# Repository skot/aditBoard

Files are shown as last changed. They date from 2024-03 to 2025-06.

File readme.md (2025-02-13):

## aditBoard
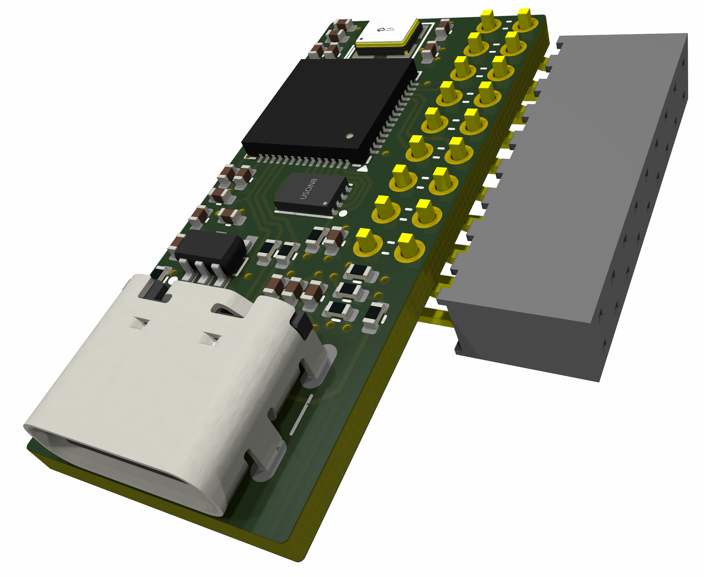
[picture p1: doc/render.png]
aditboard early render


The aditBoard is a USB adapter for Bitmain hashboards. It's based on the RaspberryPi RP2040.

The aditBoard is designed to work with the upcoming Bitcart USB, or standalone with a PC.

- For fan and PSU control check out the [AntHat](https://github.com/skot/anthat)
- Preliminary [firmware](https://github.com/The-256-Foundation/ember-one-firmware) for the aditBoard

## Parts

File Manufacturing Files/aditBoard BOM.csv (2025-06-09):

Qty | Reference | Value | PARTNO | LCSC Part
2 | C2 C4 | 30pF | 0402CG300J500NT | C1570
10 | C5 C6 C7 C10 C11 C12 C13 C14 C15 C16 | 0.1uF | CL05B104KB54PNC | C307331
2 | C8 C9 | 1uF | CL05A105KA5NQNC | C52923
2 | C17 C18 | 1uF | EMK105BJ105MV-F | C52923
2 | R2 R3 | 33 | 0402WGF330JTCE | C25105
1 | U3 | RP2040 | RP2040 | C2040
1 | U4 | AP2112K-3.3TRG1 | AP2112K-3.3TRG1 | C51118
1 | Y1 | 12MHz | X322512MSB4SI | C9002
1 | J2 | Hashboard0 | PM200-2-09-W-4.3 | C3012192
1 | J1 | USB_C_Receptacle_USB2.0 | USB4105-GF-A | C2988369
1 | U2 | W25X40CLUXIG TR | W25Q16JVUXIQ TR | C401661
1 | R1 | 10k | 0402WGF1002TCE | C25744
2 | R4 R5 | 5.1k | RMCF0402JT5K10 | C25905
3 | R25 R27 R29 | 4.7K | RC0805FR-074K7L | C25900

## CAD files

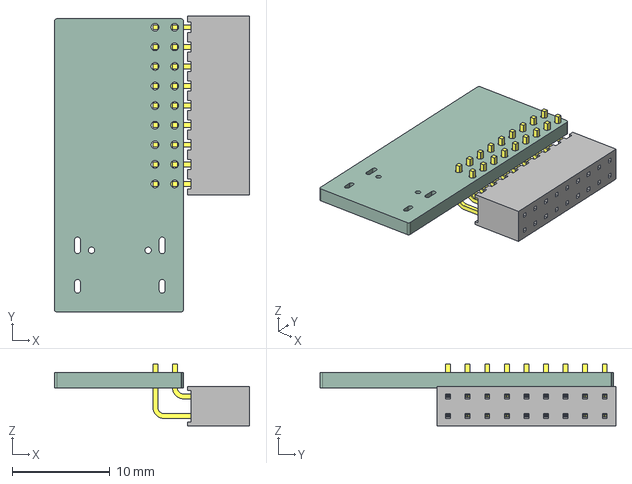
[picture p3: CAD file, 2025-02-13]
CAD/aditBoard.step
19.9 x 30.2 x 6.29 mm
SQT-109-01-F-D-RA
aditBoard_PCB

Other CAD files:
CAD/aditBoard.FCStd

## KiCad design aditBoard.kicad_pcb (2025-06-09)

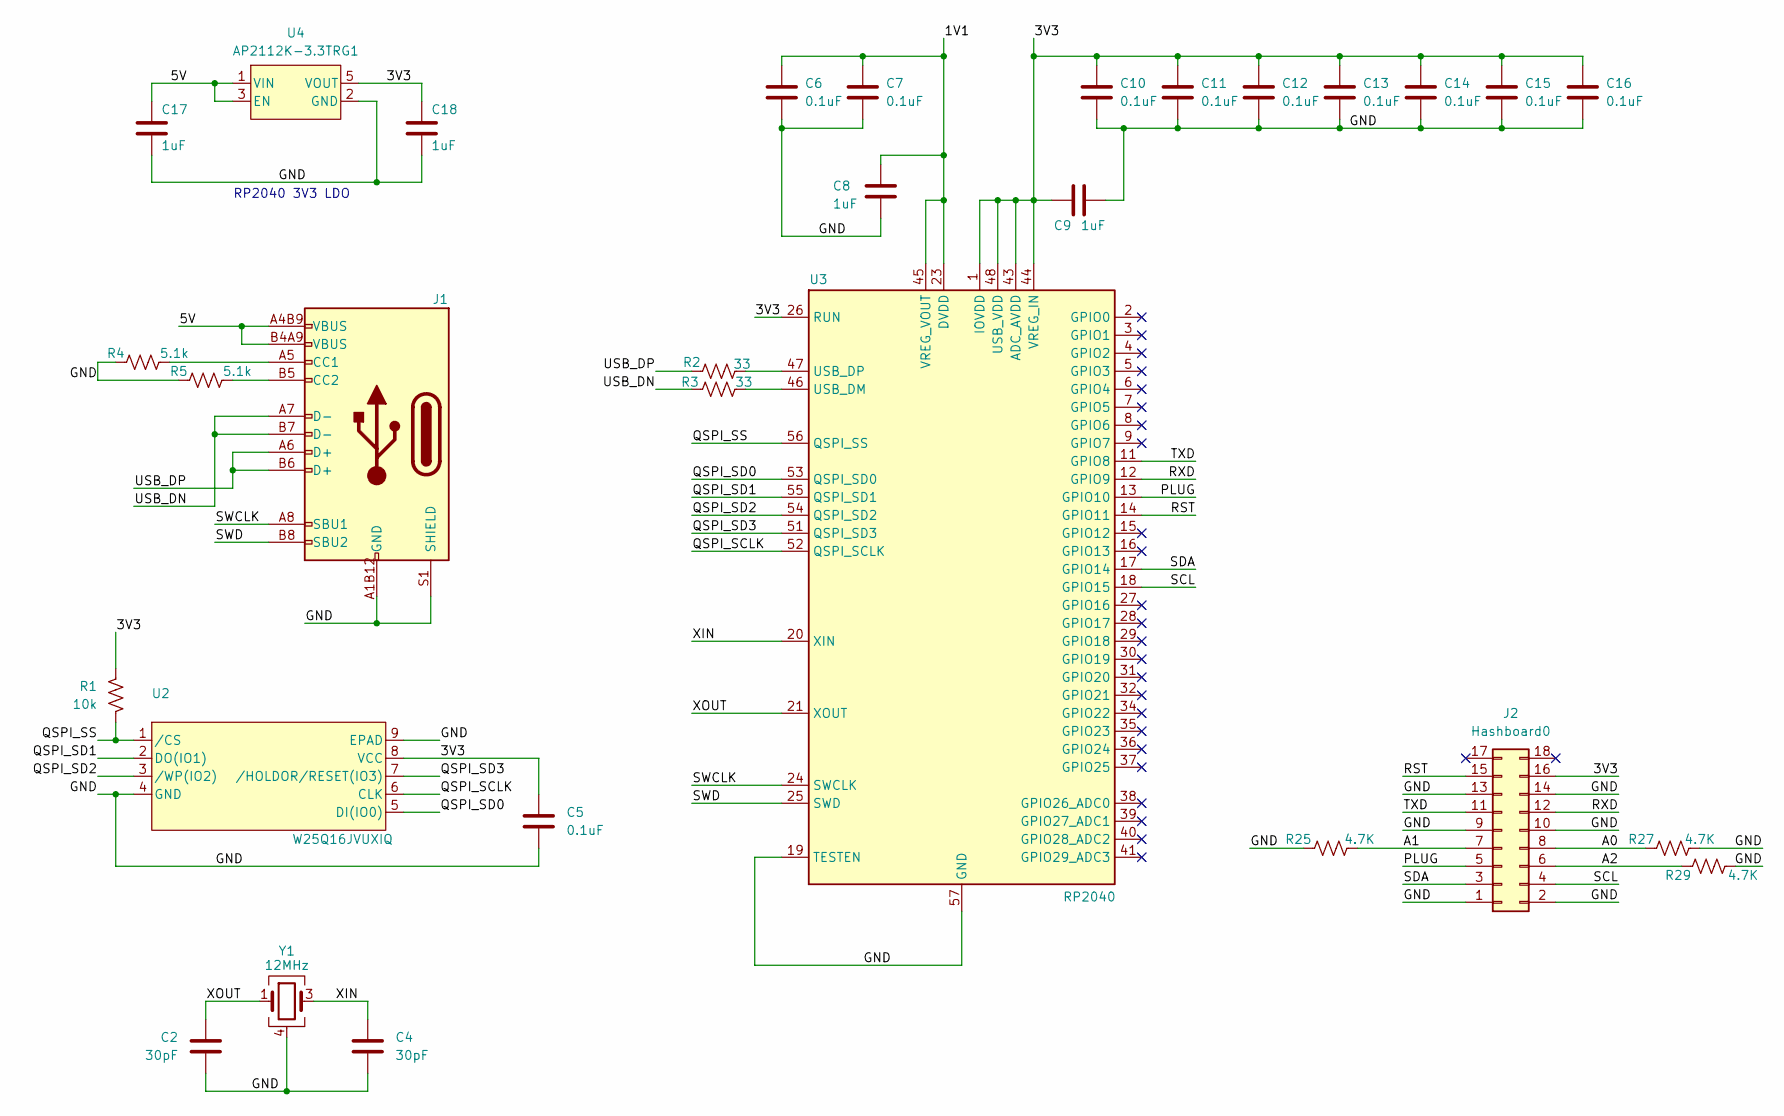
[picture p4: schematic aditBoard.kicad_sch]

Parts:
C2, C4: 30pF; C_0402_1005Metric; PARTNO 0402CG300J500NT; LCSC Part C1570
C5, C6, C7, C10, C11, C12, C13, C14, C15, C16: 0.1uF; C_0402_1005Metric; PARTNO CL05B104KB54PNC; LCSC Part C307331
C8, C9: 1uF; C_0402_1005Metric; PARTNO CL05A105KA5NQNC; LCSC Part C52923
C17, C18: 1uF; C_0402_1005Metric; PARTNO EMK105BJ105MV-F; LCSC Part C52923
J1: USB_C_Receptacle_USB2.0; USB_C_Receptacle_GCT_USB4105-xx-A_16P_TopMnt_Horizontal; PARTNO USB4105-GF-A; LCSC Part C2988369
J2: Hashboard0; PinHeader_2x09_P2.00mm_Horizontal; PARTNO PM200-2-09-W-4.3; LCSC Part C3012192
R1: 10k; R_0402_1005Metric; PARTNO 0402WGF1002TCE; LCSC Part C25744
R2, R3: 33; R_0402_1005Metric; PARTNO 0402WGF330JTCE; LCSC Part C25105
R4, R5: 5.1k; R_0402_1005Metric; PARTNO RMCF0402JT5K10; LCSC Part C25905
R25, R27, R29: 4.7K; R_0402_1005Metric; PARTNO RC0805FR-074K7L; LCSC Part C25900
U2: W25Q16JVUXIQ; USON8_L2.0-W3.0-P0.50-BL-EP; PARTNO W25Q16JVUXIQ; LCSC C2843335
U3: RP2040; QFN-56-1EP_7x7mm_P0.4mm_EP3.2x3.2mm; PARTNO RP2040; LCSC Part C2040
U4: AP2112K-3.3TRG1; SOT-25-5_L2.9-W1.6-P0.95-LS2.8-BL; PARTNO AP2112K-3.3TRG1; LCSC Part C51118
Y1: 12MHz; OSC-SMD_4P-L3.2-W2.5-BL; PARTNO X322512MSB4SI; LCSC Part C9002

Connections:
/1V1: C6.2, C7.2, C8.2, U3.23 (DVDD), U3.45 (VREG_VOUT), U3.50 (DVDD)
/3V3: C5.2, C9.1, C10.2, C11.2, C12.2, C13.2, C14.2, C15.2, C16.2, C18.1, J2.16, R1.1, U2.8 (VCC), U3.1 (IOVDD), U3.10 (IOVDD), U3.22 (IOVDD), U3.26 (RUN), U3.33 (IOVDD), U3.42 (IOVDD), U3.43 (ADC_AVDD), U3.44 (VREG_IN), U3.48 (USB_VDD), U3.49 (IOVDD), U4.5 (VOUT)
/5V: C17.1, J1.A4B9 (VBUS), J1.B4A9 (VBUS), U4.1 (VIN), U4.3 (EN)
/A0: J2.8, R27.1
/A1: J2.7, R25.2
/A2: J2.6, R29.1
/GND: C2.1, C4.1, C5.1, C6.1, C7.1, C8.1, C9.2, C10.1, C11.1, C12.1, C13.1, C14.1, C15.1, C16.1, C17.2, C18.2, J1.A1B12 (GND), J1.B1A12 (GND), J1.S1 (SHIELD), J2.1, J2.2, J2.9, J2.10, J2.13, J2.14, R4.1, R5.1, R25.1, R27.2, R29.2, U2.4 (GND), U2.9 (EPAD), U3.19 (TESTEN), U3.57 (GND), U4.2 (GND), Y1.2, Y1.4
/PLUG: J2.5, U3.13 (GPIO10)
/QSPI_SCLK: U2.6 (CLK), U3.52 (QSPI_SCLK)
/QSPI_SD0: U2.5 (DI(IO0)), U3.53 (QSPI_SD0)
/QSPI_SD1: U2.2 (DO(IO1)), U3.55 (QSPI_SD1)
/QSPI_SD2: U2.3 (/WP(IO2)), U3.54 (QSPI_SD2)
/QSPI_SD3: U2.7 (/HOLDOR/RESET(IO3)), U3.51 (QSPI_SD3)
/QSPI_SS: R1.2, U2.1 (/CS), U3.56 (QSPI_SS)
/RST: J2.15, U3.14 (GPIO11)
/RXD: J2.12, U3.12 (GPIO9)
/SCL: J2.4, U3.18 (GPIO15)
/SDA: J2.3, U3.17 (GPIO14)
/SWCLK: J1.A8 (SBU1), U3.24 (SWCLK)
/SWD: J1.B8 (SBU2), U3.25 (SWD)
/TXD: J2.11, U3.11 (GPIO8)
/USB_DN: J1.A7 (D-), J1.B7 (D-), R3.1
/USB_DP: J1.A6 (D+), J1.B6 (D+), R2.1
/XIN: C4.2, U3.20 (XIN), Y1.3
/XOUT: C2.2, U3.21 (XOUT), Y1.1
unnamed: J1.A5 (CC1), R4.2
unnamed: J1.B5 (CC2), R5.2
unnamed: R3.2, U3.46 (USB_DM)
unnamed: R2.2, U3.47 (USB_DP)

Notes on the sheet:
RP2040 3V3 LDO

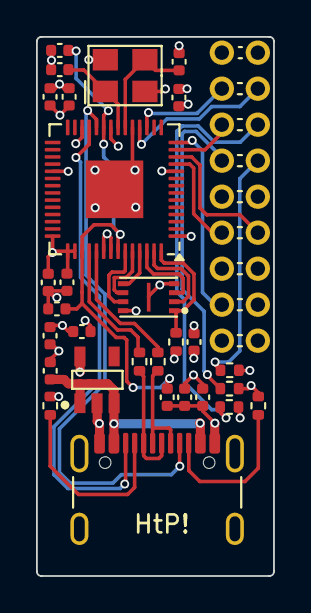
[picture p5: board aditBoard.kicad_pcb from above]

Board: 4 copper layers, 13.2 x 30.0 mm, 30 parts (0 on the bottom side), 29 nets.

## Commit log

2024-03-26 initial Import
    [aditBoard.kicad_pcb, aditBoard.kicad_sch]
2024-03-27 pretty much routed
    [aditBoard.kicad_pcb, aditBoard.kicad_sch]
2024-03-27 added artwork, DRC, LCSC BOM
    [aditBoard.kicad_pcb, aditBoard.kicad_sch]
2024-03-27 add readme
    [aditBoard.kicad_pcb, aditBoard.kicad_sch]
2024-03-27 adding checked gerbers
    [aditBoard-B_Cu.gbr, aditBoard-B_Mask.gbr, aditBoard-B_Silkscreen.gbr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]
2025-01-20 Switched SPI Flash part number for #1
    [aditBoard.kicad_pcb, aditBoard.kicad_sch]
2025-02-13 updated render to reflect the correct side for soldering the data connector.
    [aditBoard.kicad_pcb, aditBoard.kicad_sch, aditBoard.step]
2025-02-13 switched a lot of KiCad parts to STEP from WRL. This seems to make the board STEP export better.
    [aditBoard.FCStd, aditBoard.kicad_pcb]
2025-06-09 update to KiCad v9
    [aditBoard.kicad_pcb, aditBoard.kicad_sch]
2025-06-09 added BOM and cpl
    [aditBoard BOM.csv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]
